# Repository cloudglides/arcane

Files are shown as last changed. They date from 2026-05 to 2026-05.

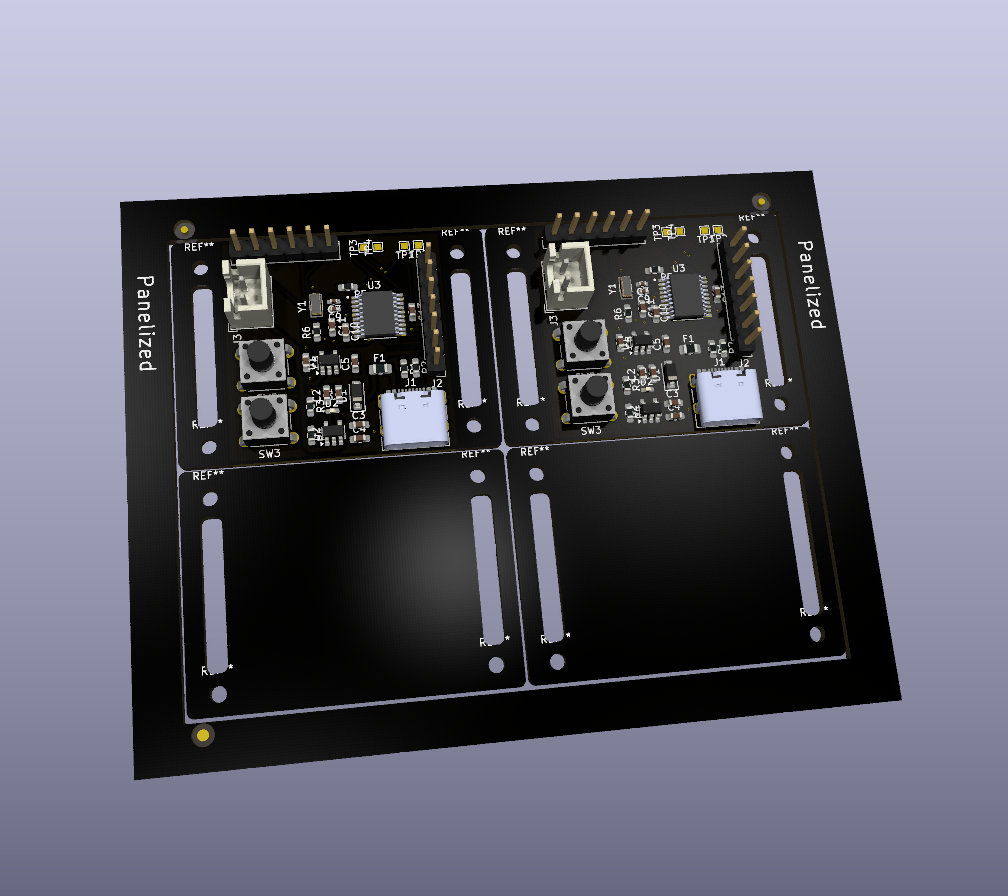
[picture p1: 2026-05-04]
production/arcane_panelized.png

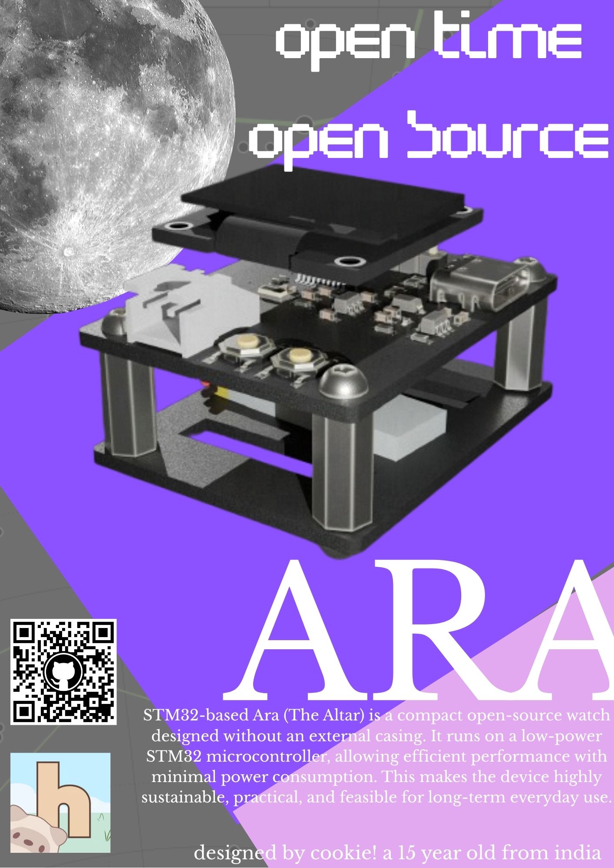
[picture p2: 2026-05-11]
zine/ara.jpg

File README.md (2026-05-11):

<h1 align="center">
  <br>
  Ara
  <br>
  Ara
  <br>
</h1>
<h4 align="center">
Open Time. Open Source.
</h4>
<div align="center">




</div>
<p align="center">
  <a href="#key-features">Key Features</a> •
  <a href="#pcb">PCB</a> •
  <a href="#credits">Credits</a> 
</p>

Ara Banner

<p>&nbsp;</p>

Ara is a custom watch PCB built around STM32, and LiPo charging into a 2 layer manufacturable board.
Built because most smartwatches don't let you know whats inside. Ara is designed from scratch open source and exactly what's needed.

To build your own, grab the KiCad files, review the schematic below, and send the panelized design to your preferred PCB fab. Flash your firmware over STM32 HEADER PINS and you're good to go.

Every smartwatch on the market is firmware locked. Ara exists to change that.

## Key Features
- **STM32** microcontroller which can go into ultra low power mode
- **Battery charging** with Integrated IC and solder pad for 1S LiPo
- **Multiple Status LEDs** for visual feedback
- **USB-C** connectivity
- **Panelized design** for cost-effective manufacturing

## PCB

Designed in KiCad with attention to power management, and IC integration. The board features a 2-layer optimized routing.

### Schematic


---

### PCB Layers

#### Layer 1


#### Layer 2


---

### Board Views

#### Front


#### Back


### Zine
ara

## Credits

This project uses:
- [KiCad](https://www.kicad.org/)
- [Blender](https://www.blender.org/) for renders
- [Hack Club Fallout](https://fallout.hackclub.com)

## License

GPL

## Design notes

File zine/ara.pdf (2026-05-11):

# OPEN TIME

# OPEN SOURCE

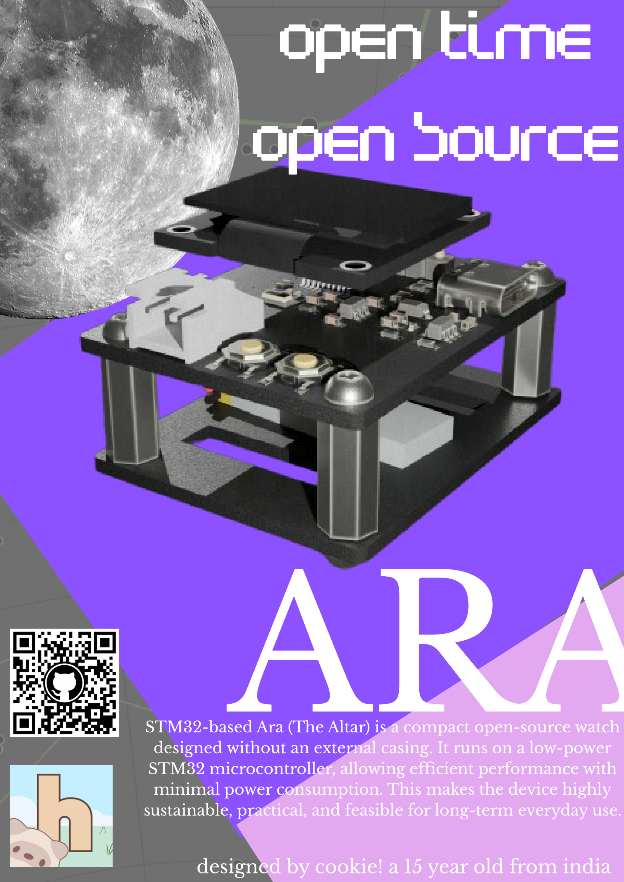
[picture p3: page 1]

# ARA

STM32-based Ara (The Altar) is a compact open-source watch designed without an external casing. It runs on a low-power STM32 microcontroller, allowing efficient performance with minimal power consumption. This makes the device highly sustainable, practical, and feasible for long-term everyday use.

### designed by cookie! a 15 year old from india

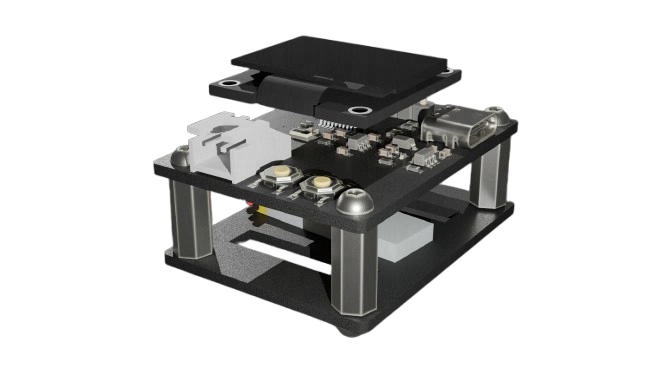
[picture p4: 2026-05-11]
assets/render-removebg-preview.png

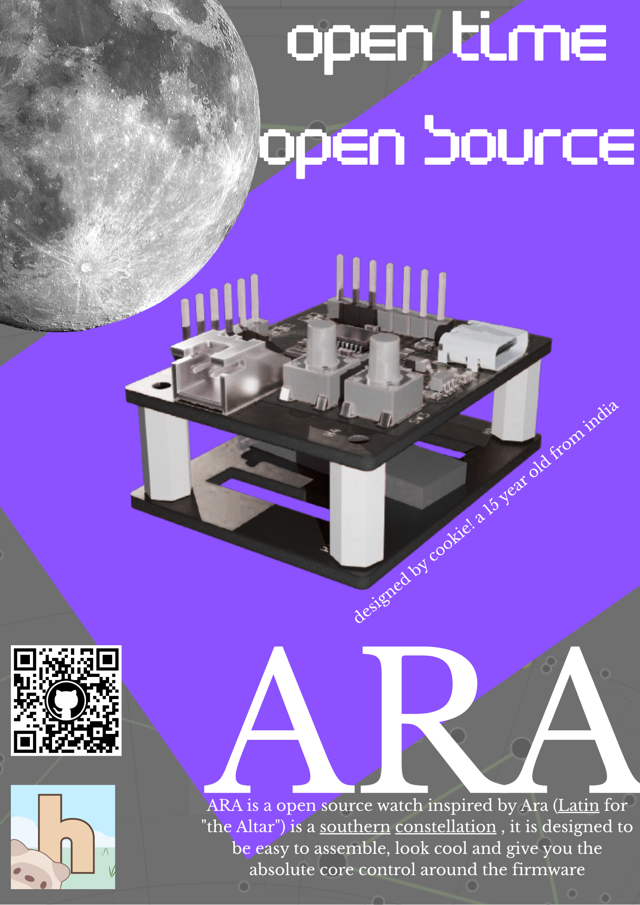
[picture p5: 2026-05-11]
assets/ara.png

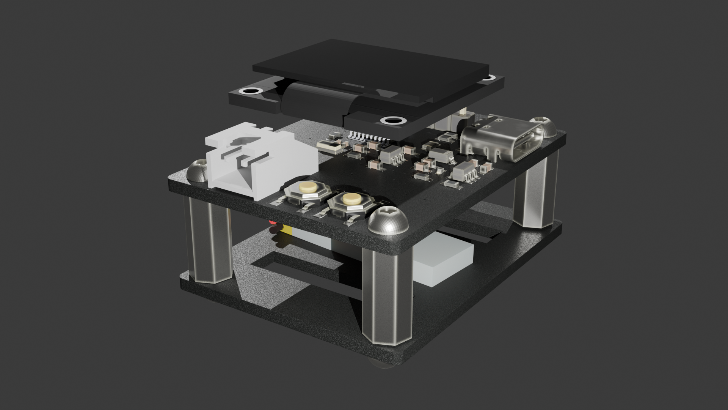
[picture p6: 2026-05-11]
blender/render.png

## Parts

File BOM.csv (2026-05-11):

NAME | UNIT | PRICE(UNIT) | TOTAL (INR) | TOTAL (USD) | SOURCE
MCP73831-2-OT | 1 | 139 | 139 | 1.53 | https://robu.in/product/mcp73831t-2aci-ot-4-2v-500ma-single-cell-li-ion-li-polymer-battery-charge-management-controller-5-pin-sot-23-microchip-technology
XC6220B331MR | 1 | 41 | 41 | 0.45 | https://robu.in/product/xc6220b331mr-g-torex-fixed-ldo-voltage-regulator-1-6v-to-6v-655mv-dropout-3-3vout-1aout-sot-25-5
STM32L031F6P6TR | 1 | 197 | 197 | 2.16 | https://robu.in/product/stm32l031f6p6tr-stmicroelectronics-arm-mcu-stm32-family-stm32l0-series-microcontrollers-arm-cortex-m0-32-bit-32-mhz-32-kb
WeAct Studio STLink-STM32 | 1 | 516 | 516 | 5.67 | https://robu.in/product/weact-studio-stlink-stm32-mini-debugger-daplink-stlink-v2-1-swd-swo-usb-to-uart-module
4.7uf 0603 caps | 4 | 1.21 | 4.84 | 0.05 | https://robu.in/product/4-7uf-4700nf-50v-capacitor-0603-smd-package-pack-of-10
SOD-123 Zener Diodes | 1 | 2.35 | 2.35 | 0.03 | https://robu.in/product/mmsz5240b-slkor-9-5v10-5v-500mw-10v-sod-123-zener-diodes-rohs
Fuse 0805 | 1 | 9 | 9 | 0.1 | https://robu.in/product/0805l200sl6ar-lute-6v-50a-2a-4a-0805-resettable-rohs
5.1K Ohm 0603 resistor | 2 | 1.31 | 2.62 | 0.03 | https://robu.in/product/rt0603brd075k1l-yageo-res-thin-film-0603-5-1k-ohm-0-1-0-1w1-10w-%C2%B125ppm-c-pad-smd-t-r
10K Ohm 0603 resistor | 1 | 0.86 | 0.86 | 0.01 | https://robu.in/product/10k-ohm-1-4w-0603-surface-mount-chip-resistor-pack-of-100
6x6x8mm Tactile Push | 3 | 1.42 | 4.26 | 0.05 | https://robu.in/product/6x6x8mm-tactile-push-button-switch-pack-of-20
32.768 kHz RTC crystal | 1 | 21 | 21 | 0.23 | https://robu.in/product/hc-49smd-6-7458mhz-20pf-20ppm-2pad-smd-smt-quartz-crystal-pack-of-2
470 Ohm 0603 resistor | 1 | 0.45 | 0.45 | 0 | https://robu.in/product/470-ohm-1-4w-0603-surface-mount-chip-resistor-pack-of-100
2K Ohm 0603 resistor | 1 | 2.8 | 2.8 | 0.03 | https://robu.in/product/rt0603brd072kl-yageo-res-thin-film-0603-2k-ohm-0-1-0-1w1-10w-%C2%B125ppm-c-pad-smd-t-r
100nf 0603 caps | 1 | 0.64 | 0.64 | 0.01 | https://robu.in/product/cc0603jrx7r7bb104-yageo-16v-100nf-x7r-%C2%B15-0603-multilayer-ceramic-capacitors-mlcc-smd-smt-rohs
10uf 0603 caps | 4 | 3.88 | 15.52 | 0.17 | https://robu.in/product/10uf-10000nf-50v-capacitor-0603-smd-package-pack-of-5
Witty Fox 110mAh Rechargeable 3.7V LiPo Battery | 1 | 114 | 114 | 1.25 | https://robocraze.com/products/witty-fox-110mah-rechargeable-3-7v-lipo-battery?_pos=1&_ss=e&_v=1.0
Band Strap Nylon | 1 | 170 | 170 | 1.87 | https://www.amazon.in/AANIJ%C2%AE-Canvas-Webbing-Collars-Leashes/dp/B08H17PDWS
PCB | 1 | 1100 | 1100 | 12.09
 |  | 2321.92 | 2341.34 | 25.73

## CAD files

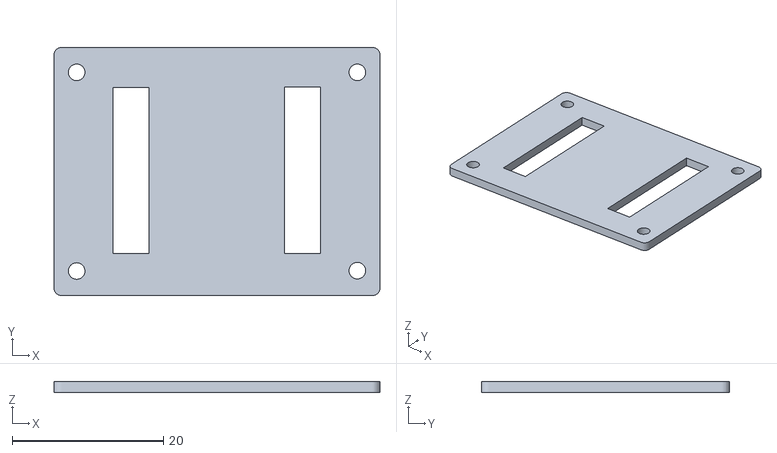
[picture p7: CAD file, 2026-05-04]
hardware/ara_bottom.stl
43.2 x 32.8 x 1.51

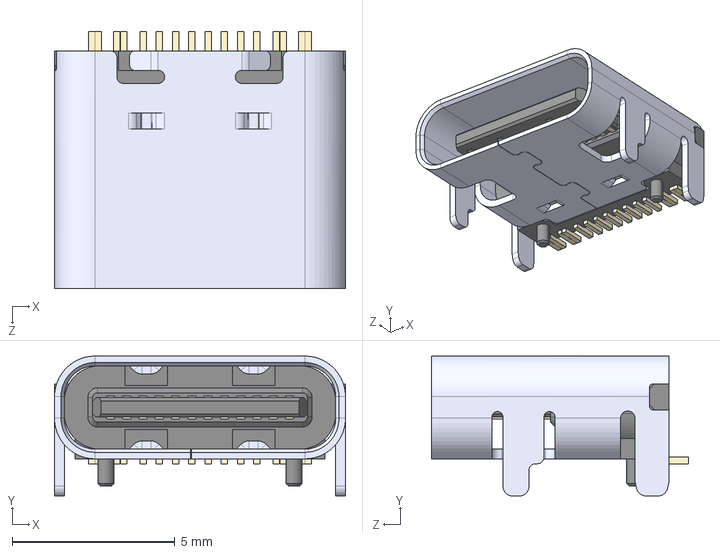
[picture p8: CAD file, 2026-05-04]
hardware/models/TYPE-C-31-M-12--3DModel-STEP-56544.STEP
8.94 x 4.30 x 7.90 mm

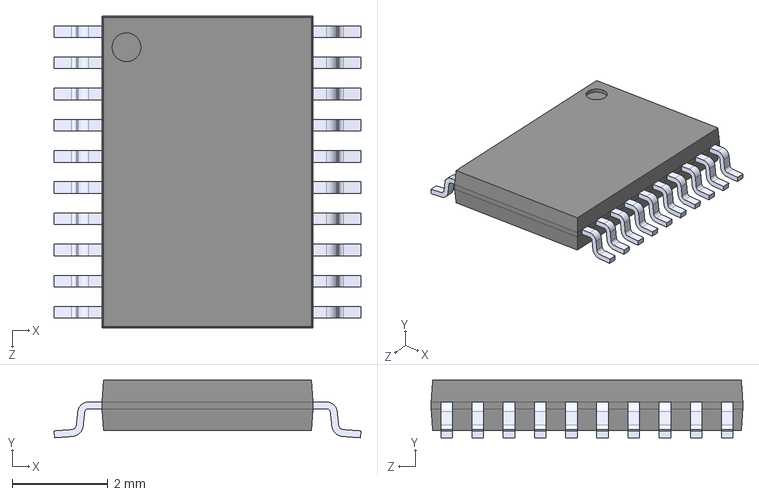
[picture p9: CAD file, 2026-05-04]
hardware/STM32L031F6P6/STM32L031F6P6.step
6.40 x 1.20 x 6.50 mm

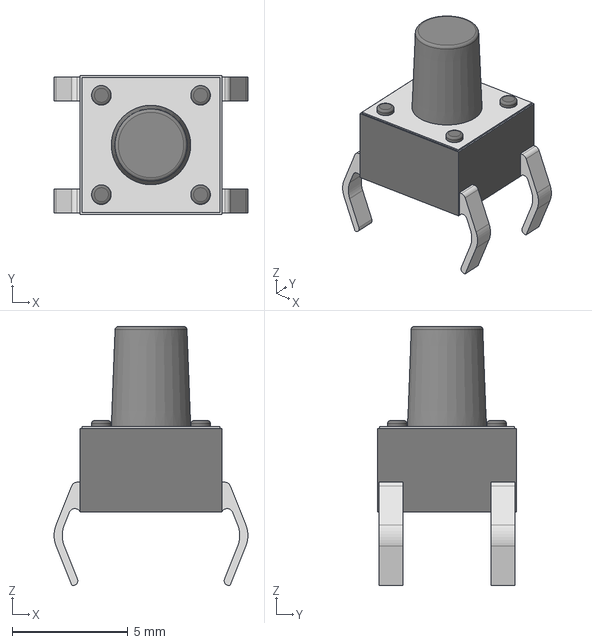
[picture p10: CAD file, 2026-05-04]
hardware/models/Tactal Switch -Thru (6mmx 6mmx8.0mm).stp
8.37 x 5.99 x 11.2 mm

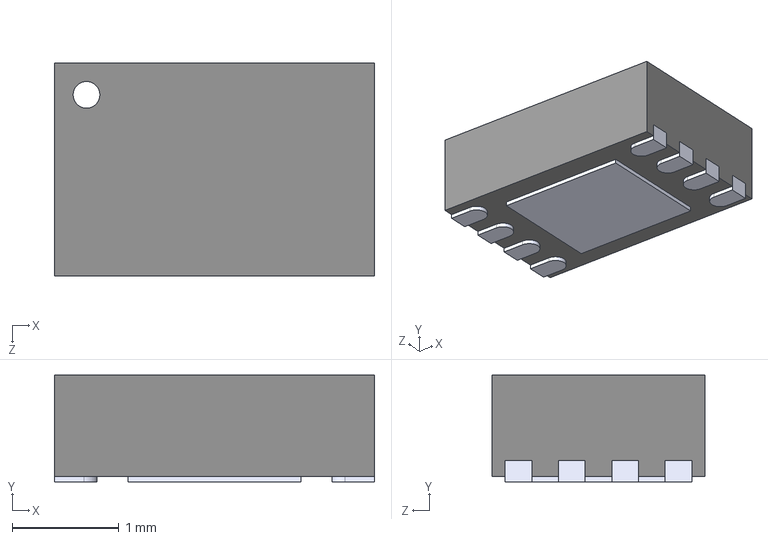
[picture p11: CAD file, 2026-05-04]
hardware/MCP73831-2ACI_MC/MCP73831-2ACI_MC.step
3.00 x 1.00 x 2.00 mm

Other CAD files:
blender/ara.blend

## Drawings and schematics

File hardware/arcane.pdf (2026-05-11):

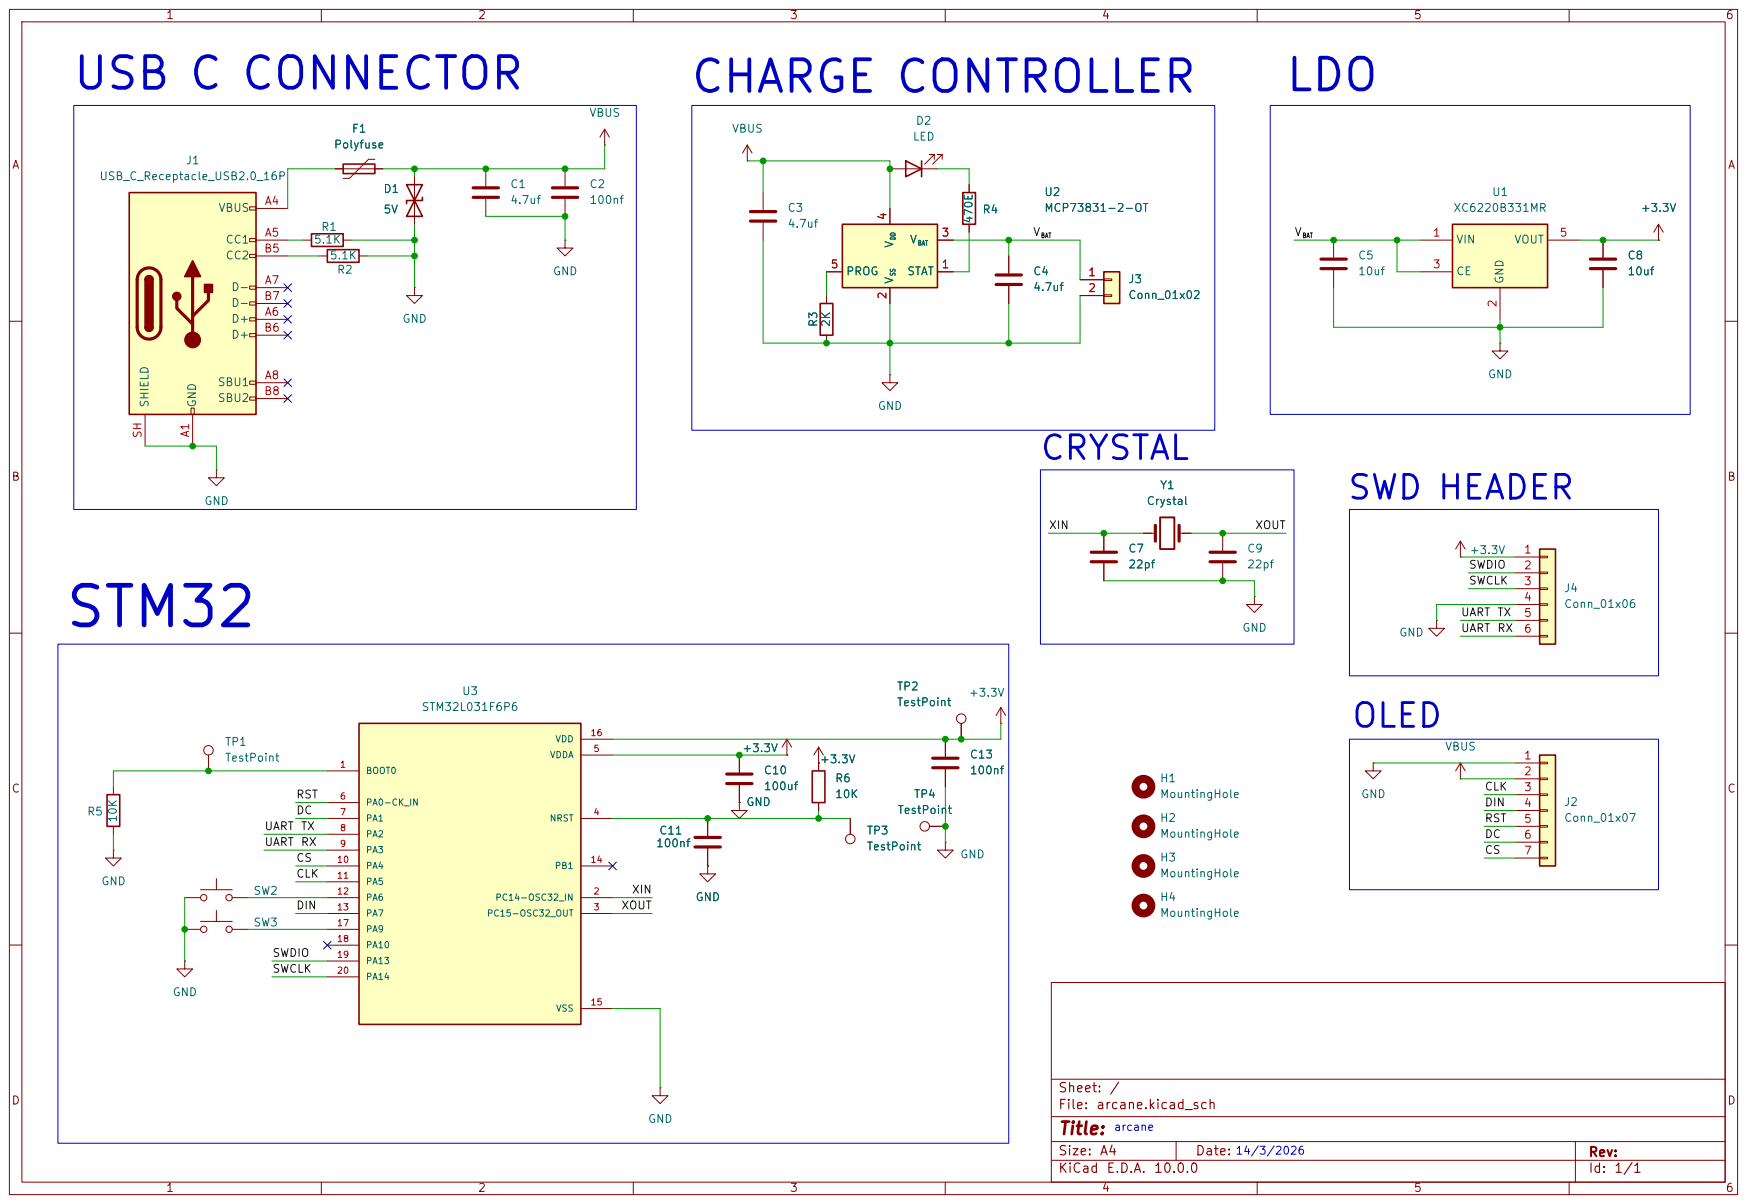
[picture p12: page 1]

SWCLK UART TX DC

Size: A4 | Rev:
KiCad E.D.A. 10.0.0 | Id: 1/1

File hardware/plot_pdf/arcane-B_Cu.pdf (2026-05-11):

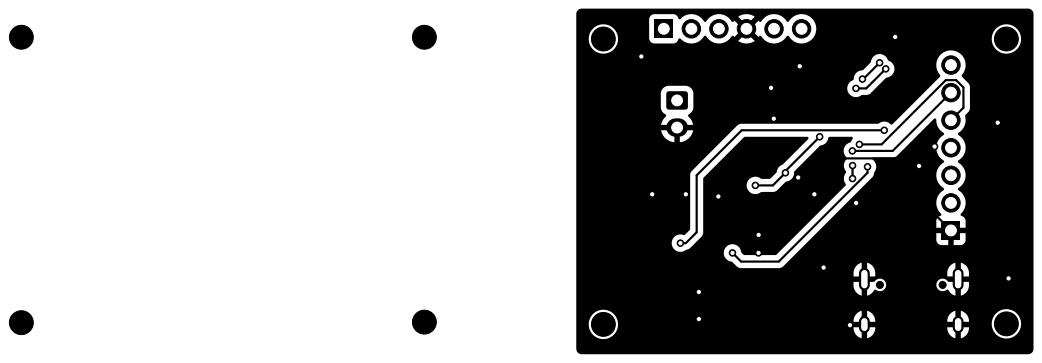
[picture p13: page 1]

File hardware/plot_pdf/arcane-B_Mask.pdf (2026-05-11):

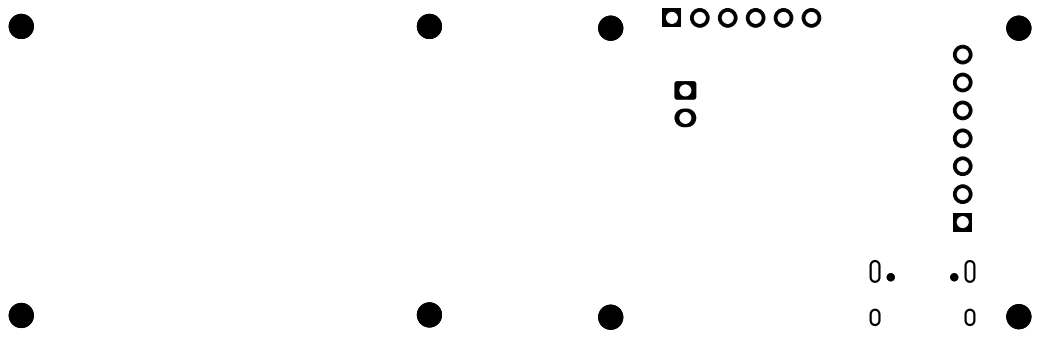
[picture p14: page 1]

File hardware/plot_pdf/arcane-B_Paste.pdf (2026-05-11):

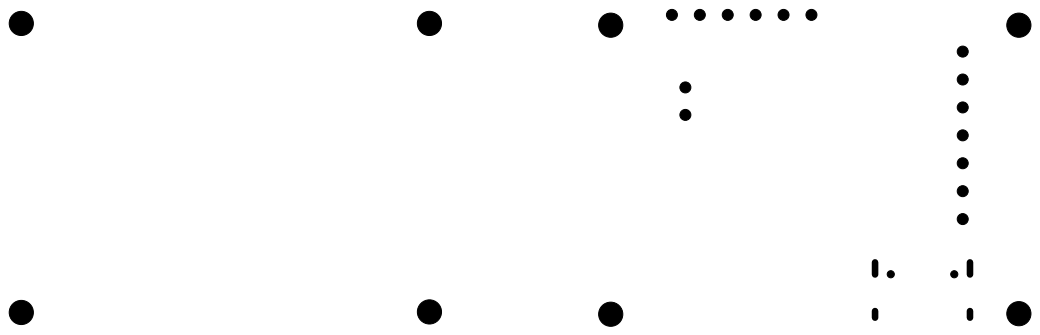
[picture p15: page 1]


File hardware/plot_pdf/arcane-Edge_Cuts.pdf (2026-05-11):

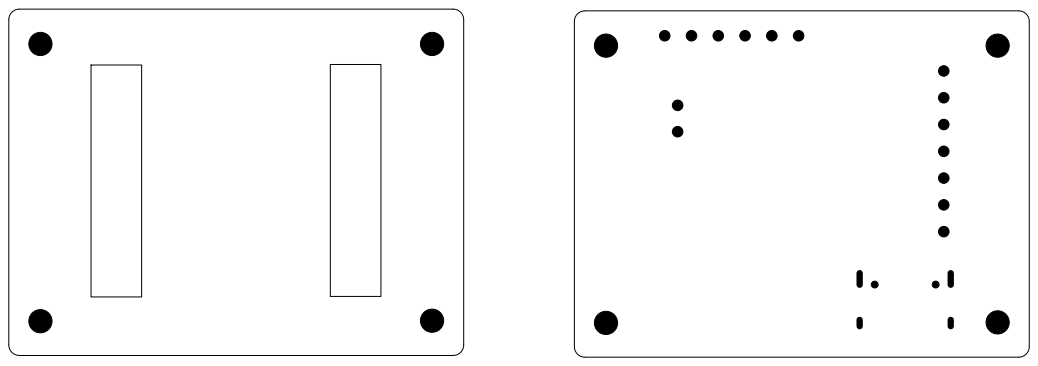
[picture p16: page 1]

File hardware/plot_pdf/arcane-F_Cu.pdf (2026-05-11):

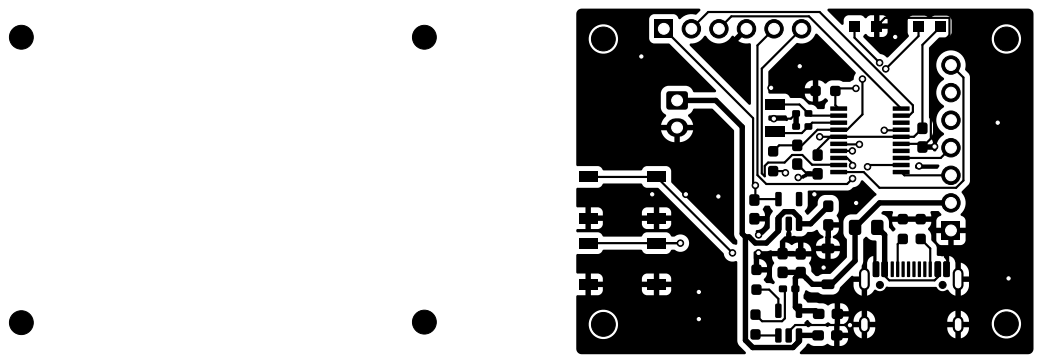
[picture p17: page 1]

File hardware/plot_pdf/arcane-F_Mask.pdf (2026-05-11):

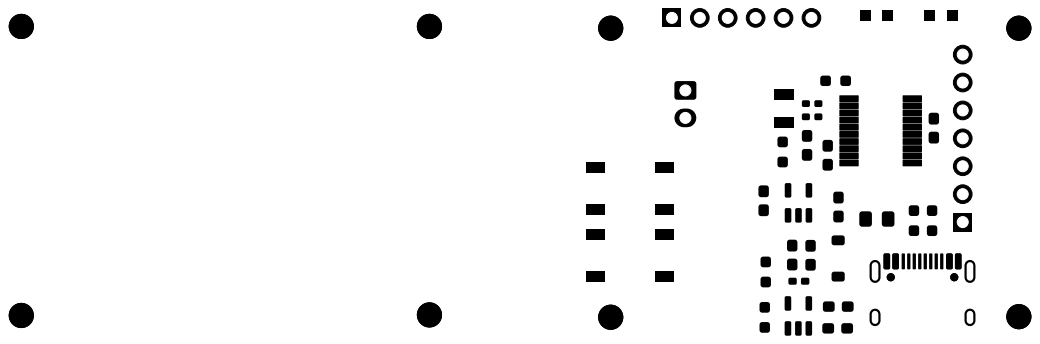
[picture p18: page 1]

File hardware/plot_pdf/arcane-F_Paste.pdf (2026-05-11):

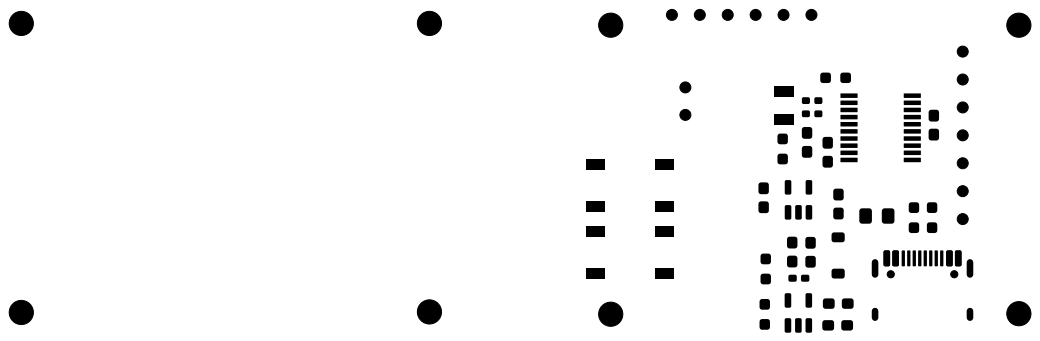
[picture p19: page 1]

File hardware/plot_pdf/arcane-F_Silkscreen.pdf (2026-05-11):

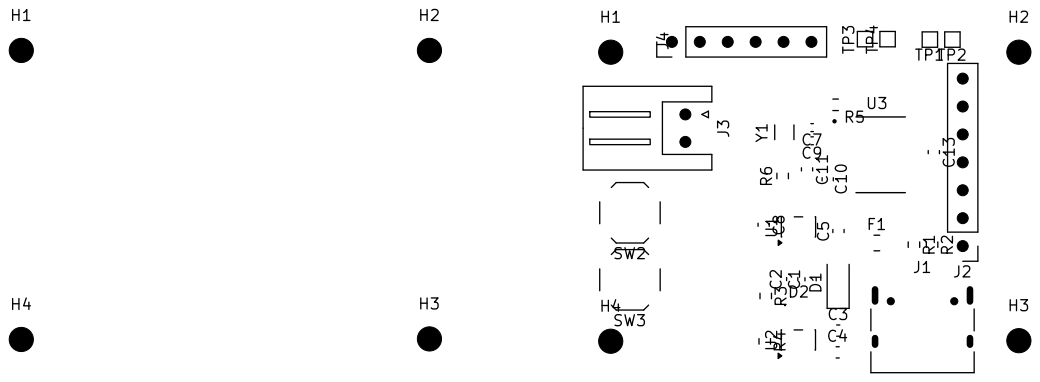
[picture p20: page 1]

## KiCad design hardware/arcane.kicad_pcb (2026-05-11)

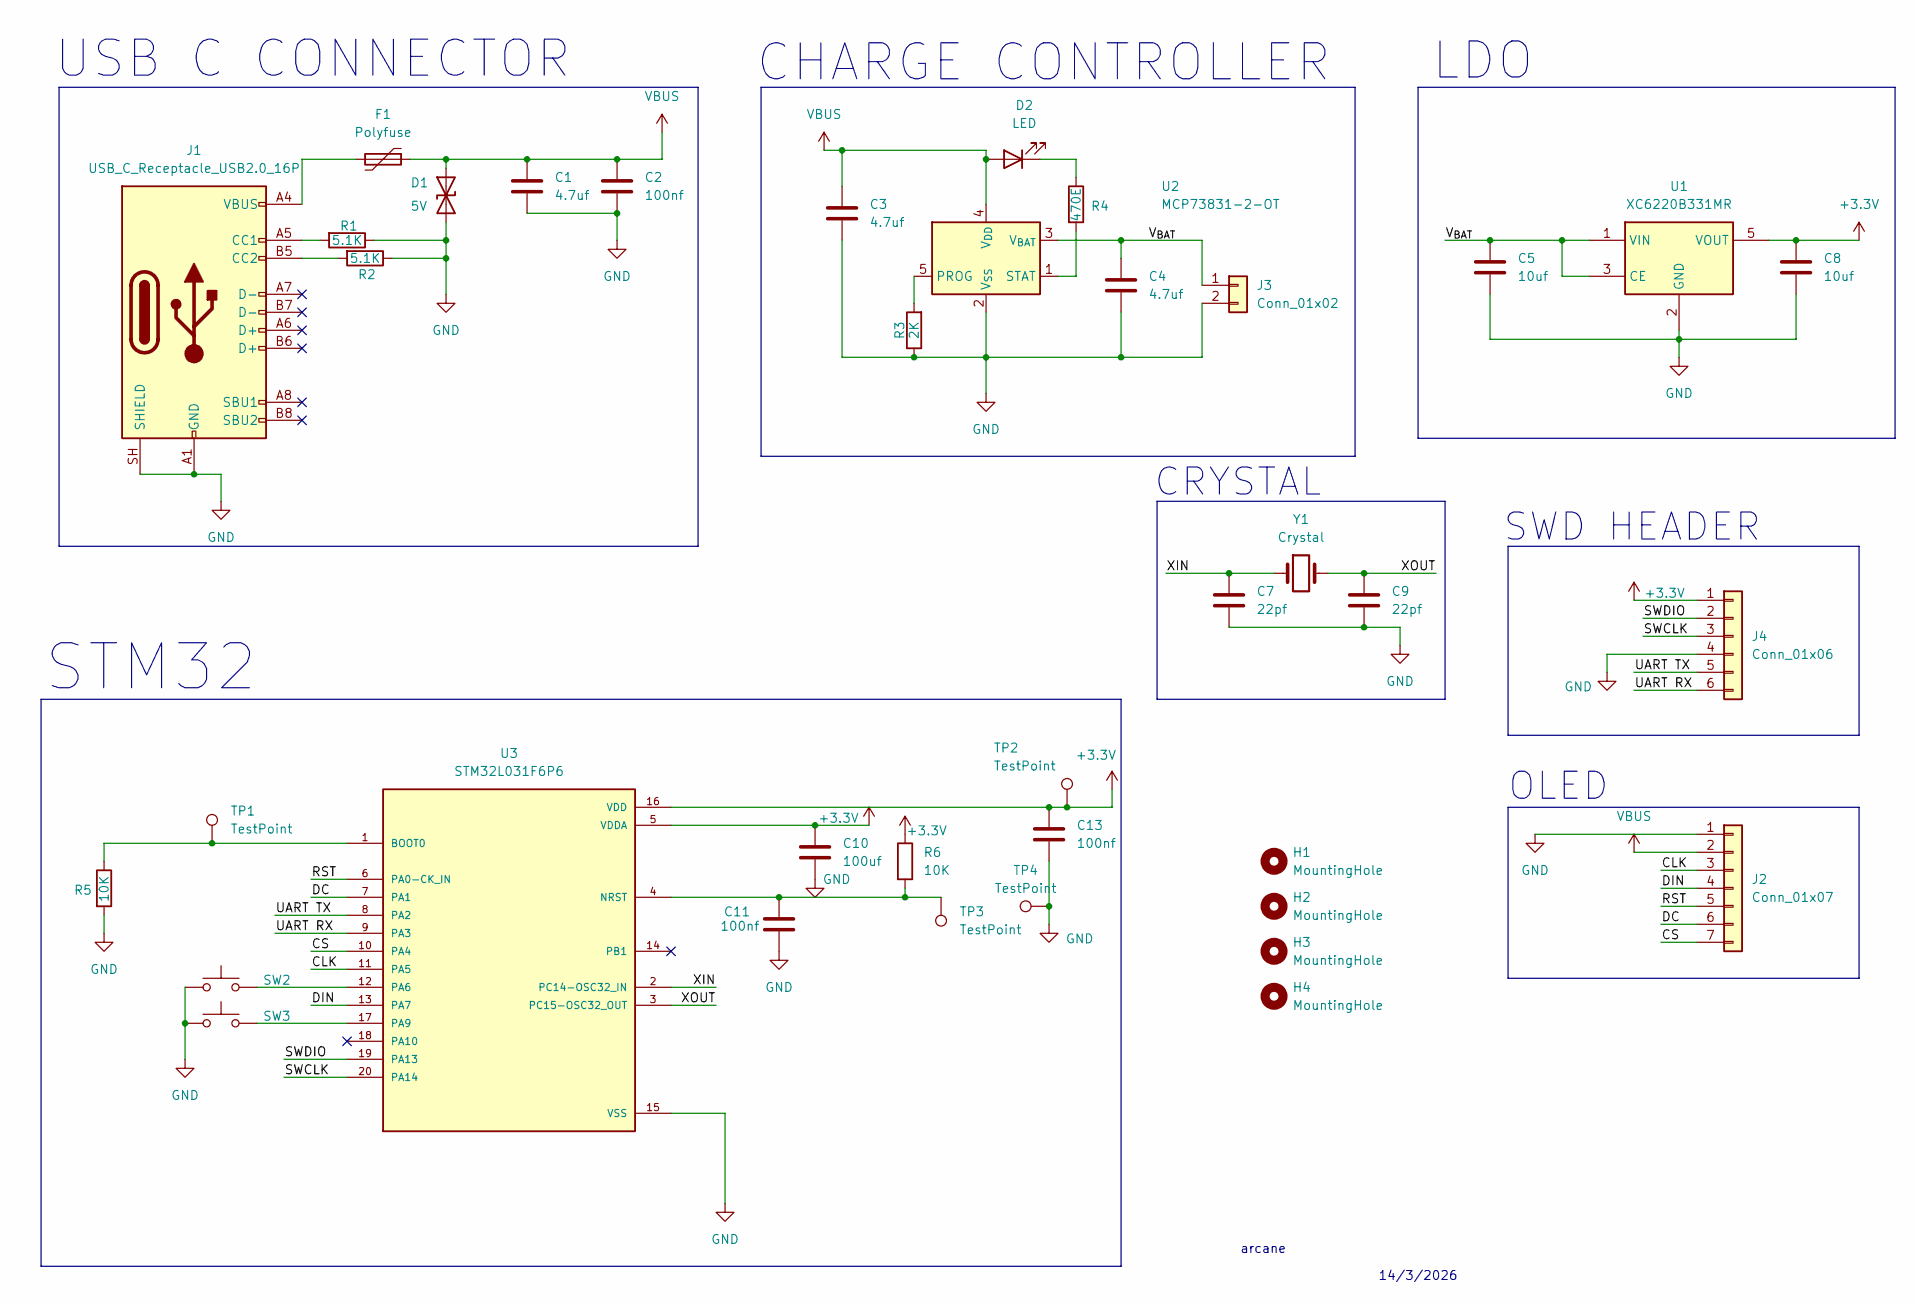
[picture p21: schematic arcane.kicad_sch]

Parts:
C1, C3, C4: 4.7uf; C_0603_1608Metric_Pad1.08x0.95mm_HandSolder
C2, C11, C13: 100nf; C_0603_1608Metric_Pad1.08x0.95mm_HandSolder
C5, C8: 10uf; C_0603_1608Metric_Pad1.08x0.95mm_HandSolder
C7, C9: 22pf; C_0402_1005Metric_Pad0.74x0.62mm_HandSolder
C10: 100uf; C_0603_1608Metric_Pad1.08x0.95mm_HandSolder
D1: 5V; D_SOD-123; LCSC Part C82044
D2: LED; LED_0402_1005Metric_Pad0.77x0.64mm_HandSolder
F1: Polyfuse; Fuse_0805_2012Metric_Pad1.15x1.40mm_HandSolder
H1, H2, H3, H4: MountingHole; MountingHole_2.2mm_M2
J1: USB_C_Receptacle_USB2.0_16P; USB_C_Receptacle_HRO_TYPE-C-31-M-12
J2: Conn_01x07; PinHeader_1x07_P2.54mm_Vertical
J3: Conn_01x02; JST_XH_S2B-XH-A_1x02_P2.50mm_Horizontal
J4: Conn_01x06; PinHeader_1x06_P2.54mm_Vertical
R1, R2: 5.1K; R_0603_1608Metric_Pad0.98x0.95mm_HandSolder
R3: 2K; R_0603_1608Metric_Pad0.98x0.95mm_HandSolder
R4: 470E; R_0603_1608Metric_Pad0.98x0.95mm_HandSolder
R5, R6: 10K; R_0603_1608Metric_Pad0.98x0.95mm_HandSolder
SW2, SW3: SW_Push; SW_SPST_TL3342
TP1, TP2, TP3, TP4: TestPoint; TestPoint_Pad_1.0x1.0mm
U1: XC6220B331MR; SOT-23-5
U2: MCP73831-2-OT; SOT-23-5
U3: STM32L031F6P6; SOP65P640X120-20N; PARTREV 6
Y1: Crystal; Crystal_SMD_3215-2Pin_3.2x1.5mm

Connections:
+3.3V: C8.1, C10.1, C13.1, J4.1, R6.1, TP2.1 (1_1), U1.5 (VOUT), U3.5 (VDDA), U3.16 (VDD)
/CLK: J2.3, U3.11 (PA5)
/CS: J2.7, U3.10 (PA4)
/DC: J2.6, U3.7 (PA1)
/DIN: J2.4, U3.13 (PA7)
/RST: J2.5, U3.6 (PA0-CK_IN)
/SWCLK: J4.3, U3.20 (PA14)
/SWDIO: J4.2, U3.19 (PA13)
/UART RX: J4.6, U3.9 (PA3)
/UART TX: J4.5, U3.8 (PA2)
/V_{BAT}: C4.1, C5.1, J3.1, U1.1 (VIN), U1.3 (CE), U2.3 (V_{BAT})
/XIN: C7.1, U3.2 (PC14-OSC32_IN), Y1.1
/XOUT: C9.1, U3.3 (PC15-OSC32_OUT), Y1.2
GND: C1.2, C2.2, C3.2, C4.2, C5.2, C7.2, C8.2, C9.2, C10.2, C11.2, C13.2, D1.2 (A2), J1.A1 (GND), J1.A12 (GND), J1.B1 (GND), J1.B12 (GND), J1.SH (SHIELD), J2.1, J3.2, J4.4, R1.1, R2.1, R3.1, R5.2, SW2.1, SW3.1, TP4.1 (1_1), U1.2 (GND), U2.2 (V_{SS}), U3.15 (VSS)
unnamed: D2.1 (K), R4.1
unnamed: F1.2, J1.A4 (VBUS), J1.A9 (VBUS), J1.B4 (VBUS), J1.B9 (VBUS)
unnamed: J1.A5 (CC1), R1.2
unnamed: J1.B5 (CC2), R2.2
unnamed: R3.2, U2.5 (PROG)
unnamed: R4.2, U2.1 (STAT)
unnamed: R5.1, TP1.1 (1_1), U3.1 (BOOT0)
unnamed: C11.1, R6.2, TP3.1 (1_1), U3.4 (NRST)
unnamed: SW2.2, U3.12 (PA6)
unnamed: SW3.2, U3.17 (PA9)
VBUS: C1.1, C2.1, C3.1, D1.1 (A1), D2.2 (A), F1.1, J2.2, U2.4 (V_{DD})

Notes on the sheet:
OLED
CRYSTAL
14/3/2026
SWD HEADER
arcane
CHARGE CONTROLLER
LDO
USB C CONNECTOR
STM32

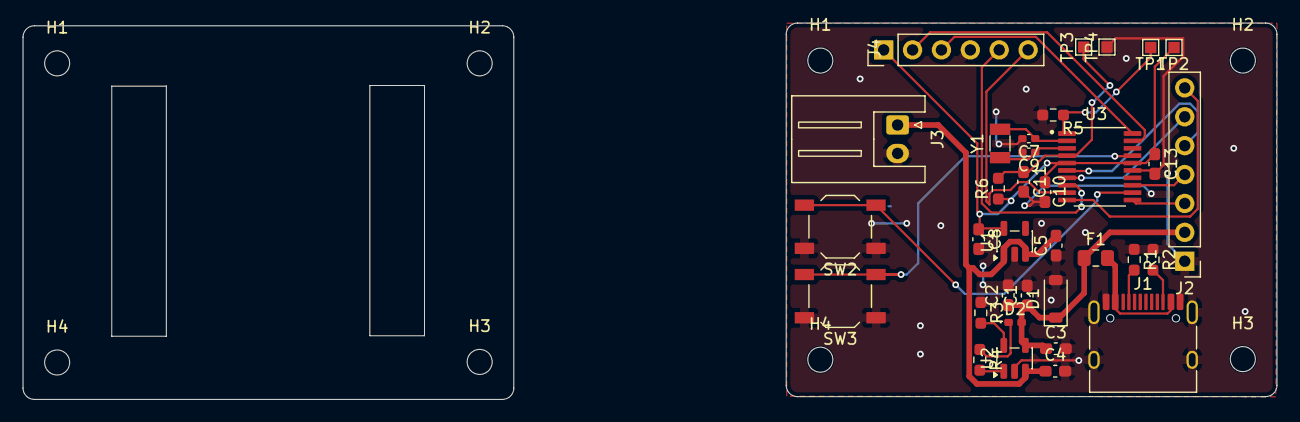
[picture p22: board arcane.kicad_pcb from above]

Board: 2 copper layers, 43.2 x 32.8 mm, 42 parts (0 on the bottom side), 25 nets.

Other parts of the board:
H1#2, H2#2, H3#2, H4#2: MountingHole; MountingHole_2.2mm_M2

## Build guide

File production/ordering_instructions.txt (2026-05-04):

Ordering Instructions:
Panel dimensions: 100.55 x 79.95 mm.
Solder Mask: Red (Default)
Silkscreen: White (Default)
Layers: 2
Finish: HASL Lead-free (Default)
Thickness: 1.6mm (Default)
Copper weight: 1oz (Default)
Minimum track width: 0.20mm (7.87mil)
Minimum via drill: 0.30mm (11.81mil)

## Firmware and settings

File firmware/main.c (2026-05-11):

#include "stm32f1xx_hal.h"   
void SystemClock_Config(void);
static void MX_GPIO_Init(void);

int main(void)
{
    HAL_Init();
    SystemClock_Config();
    MX_GPIO_Init();

    while (1)
    {
        HAL_GPIO_TogglePin(GPIOC, GPIO_PIN_13);
        HAL_Delay(500);
    }
}

static void MX_GPIO_Init(void)
{
    __HAL_RCC_GPIOC_CLK_ENABLE();

    GPIO_InitTypeDef GPIO_InitStruct = {0};

    GPIO_InitStruct.Pin = GPIO_PIN_13;
    GPIO_InitStruct.Mode = GPIO_MODE_OUTPUT_PP;
    GPIO_InitStruct.Speed = GPIO_SPEED_FREQ_LOW;

    HAL_GPIO_Init(GPIOC, &GPIO_InitStruct);
}

void SystemClock_Config(void)
{
    RCC_OscInitTypeDef RCC_OscInitStruct = {0};
    RCC_ClkInitTypeDef RCC_ClkInitStruct = {0};

    RCC_OscInitStruct.OscillatorType = RCC_OSCILLATORTYPE_HSI;
    RCC_OscInitStruct.HSIState = RCC_HSI_ON;
    RCC_OscInitStruct.HSICalibrationValue = RCC_HSICALIBRATION_DEFAULT;
    RCC_OscInitStruct.PLL.PLLState = RCC_PLL_NONE;

    HAL_RCC_OscConfig(&RCC_OscInitStruct);

    RCC_ClkInitStruct.ClockType = RCC_CLOCKTYPE_HCLK | RCC_CLOCKTYPE_SYSCLK
                                | RCC_CLOCKTYPE_PCLK1 | RCC_CLOCKTYPE_PCLK2;

    RCC_ClkInitStruct.SYSCLKSource = RCC_SYSCLKSOURCE_HSI;
    RCC_ClkInitStruct.AHBCLKDivider = RCC_SYSCLK_DIV1;
    RCC_ClkInitStruct.APB1CLKDivider = RCC_HCLK_DIV1;
    RCC_ClkInitStruct.APB2CLKDivider = RCC_HCLK_DIV1;

    HAL_RCC_ClockConfig(&RCC_ClkInitStruct, FLASH_LATENCY_0);
}

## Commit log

2026-04-06 inital commit
    [113991054.step, Seeed Studio XIAO nRF52840.step, arcane.kicad_pcb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]
2026-04-07 update: panelize PCB for prod
    [arcane.kicad_pcb, arcane.kicad_sch, arcane_panelized.kicad_pcb]
2026-04-07 add: gerber files
    [arcane_panelized.kicad_pcb]
2026-04-07 update: zine & bom
    [BOM.csv]
2026-04-08 update: BOM && firmware
    [BOM.csv]
2026-04-08 fix: BOM source
    [BOM.csv]
2026-05-04 migrate to stm32
    [113991054.step, MCP73831-2ACI_MC.step, STM32L031F6P6.step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]
2026-05-11 update: zine, firmware and gerber
    [BOM.csv, ara.blend, arcane.kicad_pcb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]
